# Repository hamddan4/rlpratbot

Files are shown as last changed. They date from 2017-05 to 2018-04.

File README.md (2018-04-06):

# rlpratbot

Remote Autonomous Transporter

A project to remotely control a small vehicle using a Telegram bot through an Arduino board.

All the schematics are provided in the "Images & Fritzing" folder. Code for the sender and receiver/controller board can be found in the "Code" folder.

This project was part of a university course.

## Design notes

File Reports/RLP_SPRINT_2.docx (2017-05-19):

RAT

A remotely controlled robot that travels to a specified location while avoiding obstacles.
________________________________________________________________

# Project description

The sole purpose of RAT is to transport an object from one point to another. To accomplish this, RAT will wait until it remotely receives a coordinate to go to, then it'll travel there while avoiding any obstacle in the way. It'll also periodically send its current position to the remote controller, so that the robot can be localized at any time.

Below is a detailed description on how we plan to carry out these functionalities:

- Movement: RAT will be able to move using two DC motors (with wheels attached) controlled by a motor driver board. This setup makes it possible for RAT to move forwards and backwards with an adjustable speed. Rotation will be accomplished by activating only one of the two motors.
- Remotely sending and receiving data: We'll use two transceivers controlled by two Arduino UNO boards. One of them will be located in the robot, and the other will be connected to the computer used to send the coordinates and receive the current robot position.
- Route tracing: When RAT receives an objective coordinate, it'll get its current position and orientation using a GPS and a magnetometer respectively. It'll then trace a straight line from its current position to the objective coordinate, calculate the direction, and rotate accordingly. When it determines it's facing the correct direction, it'll start moving forward until an obstacle is found or the objective coordinates have been reached. Periodical checks will be made to make sure it's not going offtrack.
- Obstacle avoiding: RAT will be able to detect nearby obstacles using a sonar. Once an obstacle is detected, it'll try to overcome it and then resume its original path. We still don't know a lot about how to code this, but we've been promised we're going to be taught.

Note on the limitations of the distance traveled:

The precision of the GPS used is around 3m, so RAT's duty is to land inside an area of 3m around the specified point. Specifying points too close to RAT would make it
The transceiver used has a range of about 100m, so making RAT go towards points farther than that leads to losing all kind of communication with it. It could still, in principle, autonomously get to its objective, and then receive new orders from a different computer nearby.

# Electronic components

- Arduino UNO (2x) (one of them is of our own, it'll be used to send data from the computer to the robot using the transceiver)
- nRF24L01P+ (Transceiver) (2x)
- L293D (Motor Driver Board)
- HC-SR04 (Sonar)
- Adafruit Ultimate GPS Logger Shield
- DC motor (2x)
- Magnetometer (not yet received, it'll not be taken into account for the connections scheme below since we don't know the model)

# Scheme

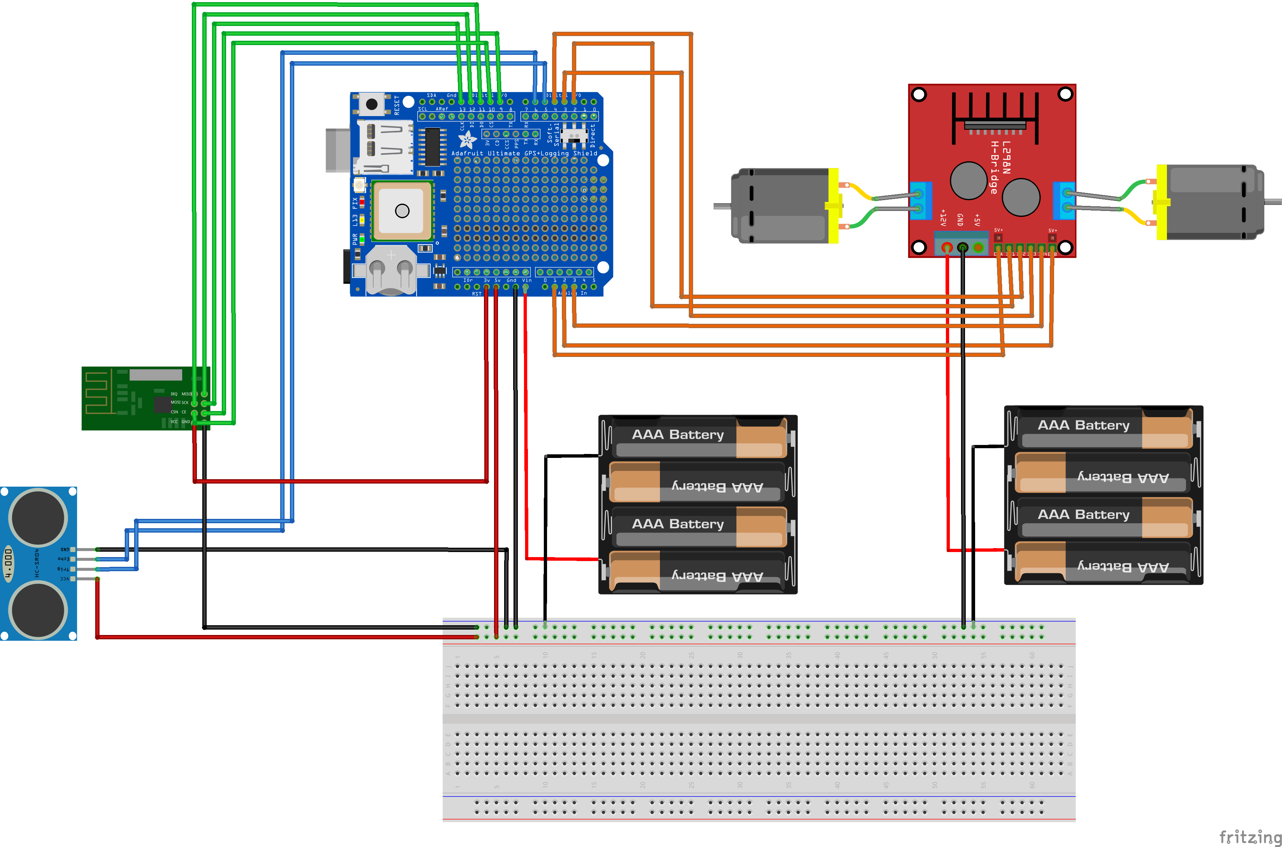
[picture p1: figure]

Notes:

- All red wires go to Vcc (5V for all the components except the transceiver which goes to the 3.3V pin).

- All black wires go to GND.

- All the AAA batteries shown in the scheme are 1.2V AA batteries in actuality.

- The GPS shield uses digital pins 0, 1, 7 and 8.

Connections:

Sonar (blue)

Trigger Pin -> Digital Pin 5 (PWM)

Echo Pin -> Digital Pin 6 (PWM)

Motor Driver (orange)

ENA -> Analogic Pin A1 (Digital Pin 15)

ENB -> Analogic Pin A2 (Digital Pin 16)

IN1 -> Digital Pin 2

IN2 -> Digital Pin 3 (PWM)

IN3 -> Digital Pin 4

IN4 -> Analogic Pin A3 (Digital Pin 17)

Transceiver (green)

CE Pin -> Digital Pin 9 (PWM)

CSN Pin -> Digital Pin 10 (PWM)

SCK Pin -> Digital Pin 13

MOSI Pin -> Digital Pin 11 (PWM)

MISO Pin -> Digital Pin 12

# Extra components and 3D pieces

- Wheel for DC motor (2x) They'll be connected to the motors to allow RAT to move on ground.
- Caster wheel A support wheel which will be placed on the back of the robot.
- 4 AA Battery Holder (2x) Used to conveniently hold 4 AA batteries in series so that they produce 5V of voltage.
- 1.2V AA Rechargeable Battery (8x) 4 of them them are to power the Arduino board, the other 4 to power the motors.

List of 3D pieces:

No. | Description | Image

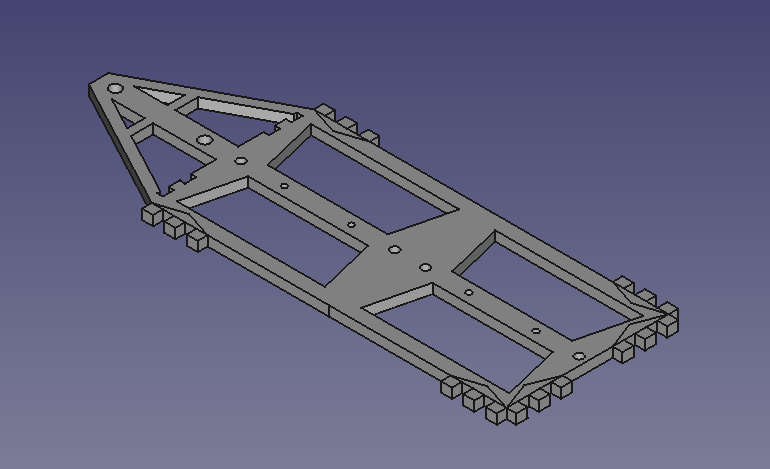
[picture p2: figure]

1 | Base of the robot. Here we'll attach both the Battery Holder and the Caster Wheel.

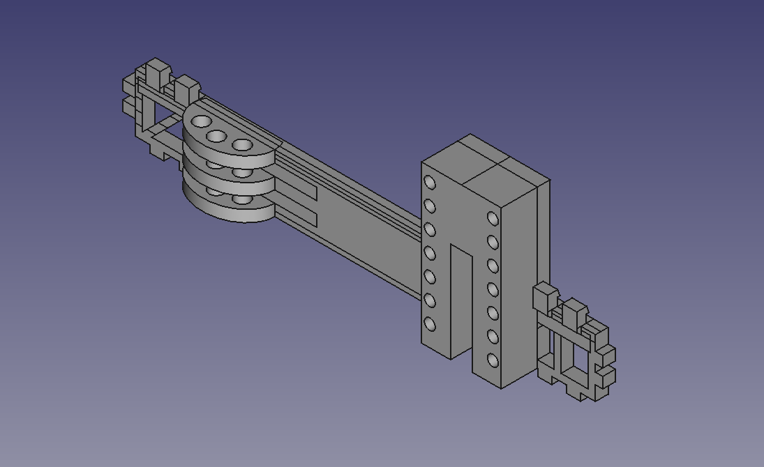
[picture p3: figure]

2 | Laterals of the robot. Here we'll attach the motors. ...and a mystery piece, coming up next sprint!

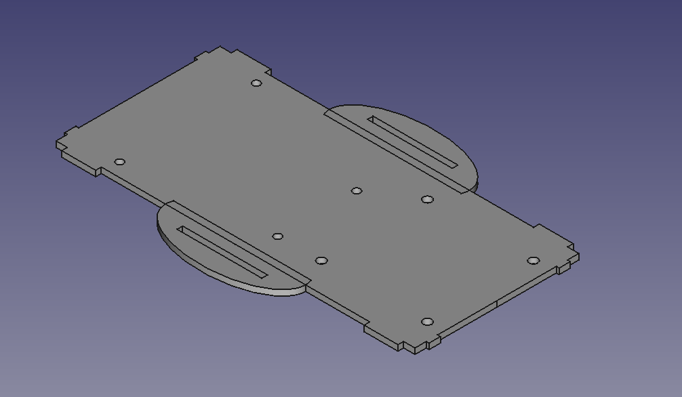
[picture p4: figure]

3 | Cover of the robot. Here we'll attach both the Arduino UNO board and the Motor Driver Board.

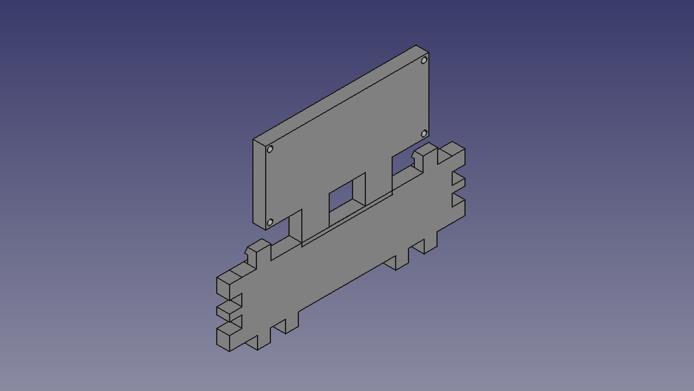
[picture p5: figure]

4 | Front of the robot. Here we'll attach the Sonar.

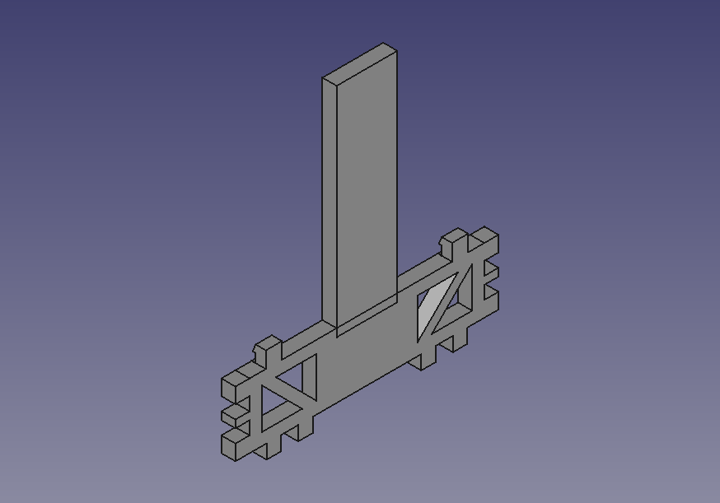
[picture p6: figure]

5 | Back of the robot. Here we'll attach the Transceiver.

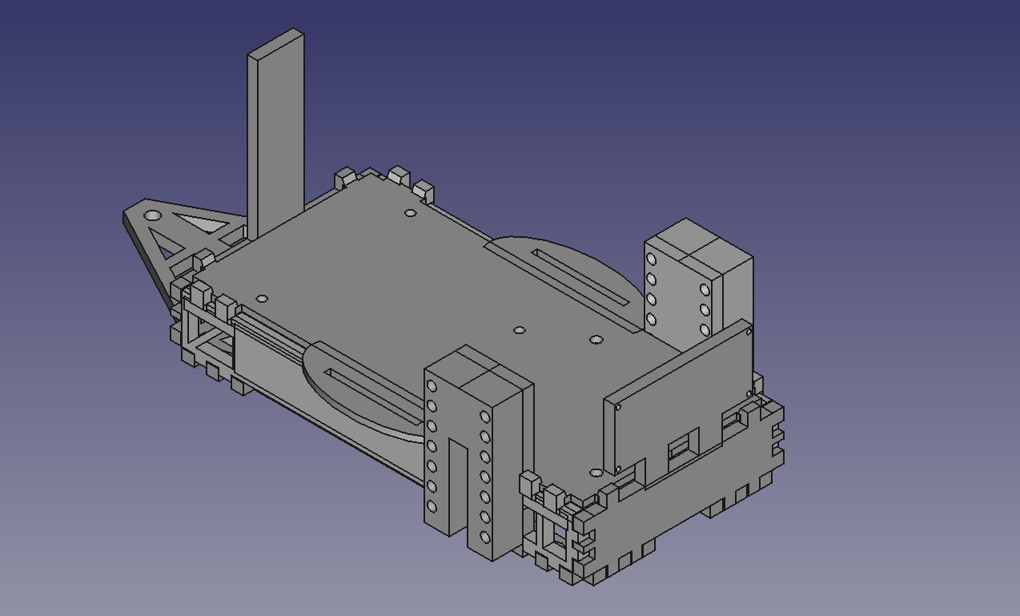
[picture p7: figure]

ALL | Overall view of the structure.

Note:

We'll join all the pieces together by sticking their respective hooks and ledges with superglue. However, the cover will use Snap-fit to make it easy to put it in and out, since the Arduino Board and the batteries are inside the robot, and we'll want to have easy access to them.

# Foreseen risks and contingency plan

No. | Description | Probability | Impact | Contingency plan
1 | We don't receive the magnetometer | Low | High | Use trial and error to determine the current orientation.
2 | The magnetometer hasn't got enough precision | Medium | Medium | Direction checks should be done very frequently (stopping the robot).
3 | The motors are not firmly fixed (and they make the robot tilt to the right or left instead of going in a straight line) | Medium | Medium | Redesign motor attachment to the robot and/or use superglue.
4 | Misalignment or rupture of the snap-fit joints (between the cover and lateral 3D pieces). | High | Low | 1. Redesign the joints and reprint the pieces. 2. (In case 1 keeps failing) Design and print a hinge which will be used to attach the cover with the laterals. 3. (In case 2 were to fail too) Just come up with a different way of accessing the insides of the robot.
5 | Misalignment or rupture of the joints to be sticked with superglue. | Medium | Medium | Redesign the joints and reprint the pieces.

References

This project has been inspired by the following Internet projects:

(http://www.instructables.com/id/Arduino-Powered-Autonomous-Vehicle/)

(http://www.robotshop.com/letsmakerobots/fundamentals-a-gps-guided-vehicle)

http://www.instructables.com/id/Arduino-Powered-Autonomous-Vehicle/

http://www.robotshop.com/letsmakerobots/fundamentals-a-gps-guided-vehicle

(http://www.instructables.com/id/Arduino-Powered-Autonomous-Vehicle/)

(http://www.robotshop.com/letsmakerobots/fundamentals-a-gps-guided-vehicle)

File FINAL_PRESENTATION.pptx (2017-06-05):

## RAT

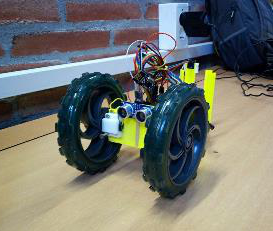
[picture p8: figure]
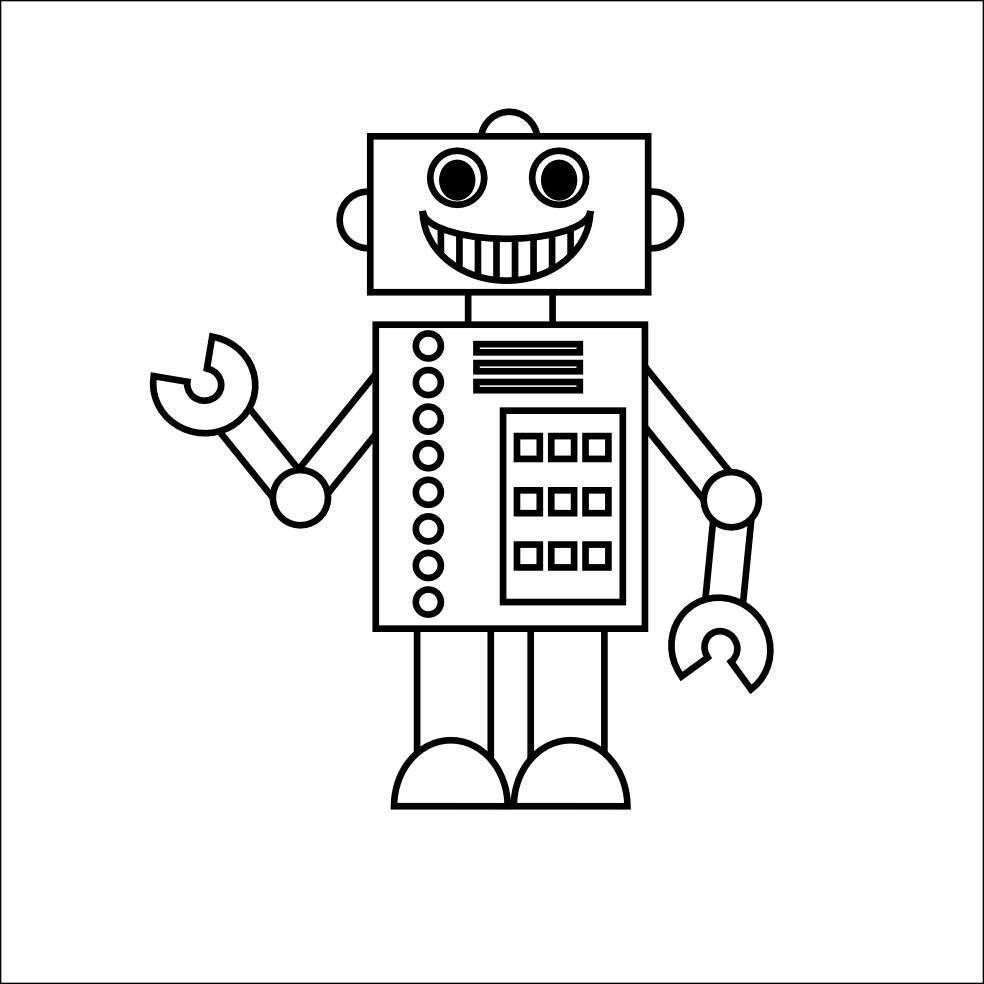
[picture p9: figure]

Adrià Rico Blanes (1391488)
Daniel Azemar i Carnicero (1390451)
Sergi Pous Mateo (1390450)
Jialuo Chen (1390203)

#Cotxe autònom controlat via Transceiver per un ordinador, utilitzarà sensors d’orientació i GPS per saber on està en cada moment.

Robòtica, llenguatge I planificació – Enginyeria informàtica - uab

## Esquema de components

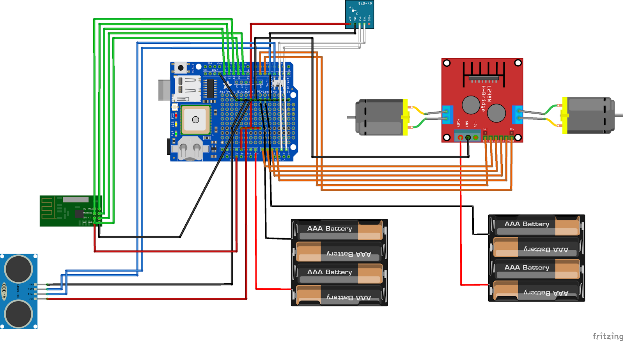
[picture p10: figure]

## 3D Design

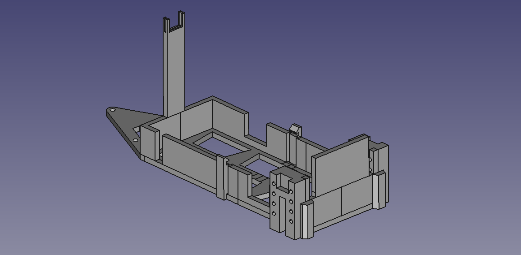
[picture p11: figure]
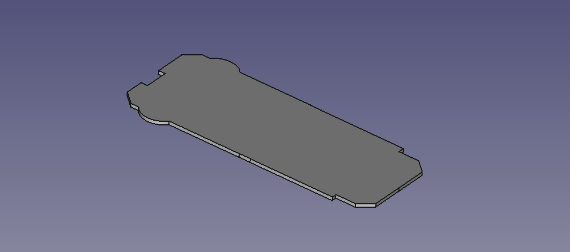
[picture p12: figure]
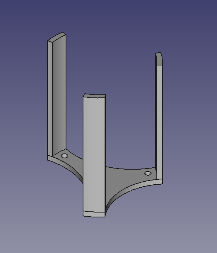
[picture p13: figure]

## 3D Design

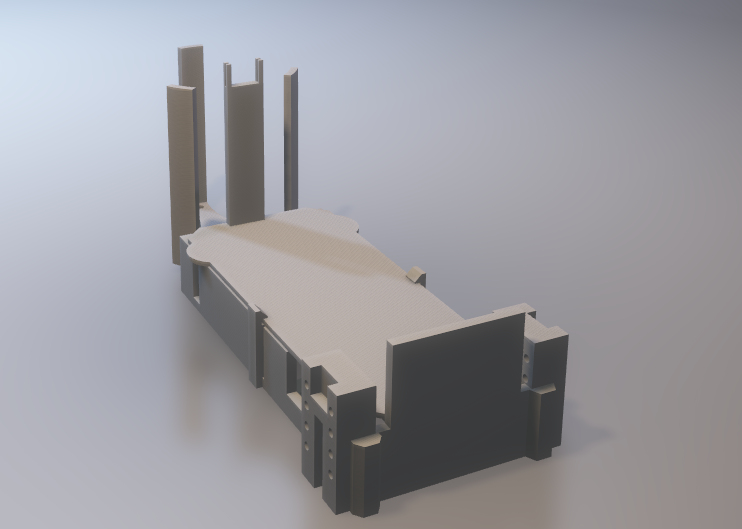
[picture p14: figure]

## 3D Design

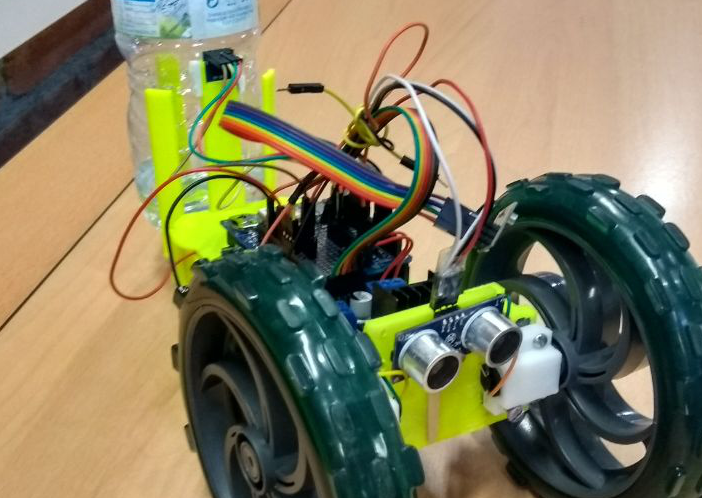
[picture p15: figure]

## Programació

Obstacle?

Order type

Loop

Get GPS

Get SONAR

Yes

OBSTACLE AVOIDANCE

Go to location

Angle OK?

Speed change

Change speed

Yes

Avoiding?

No

Movement

Obey

Get Magnetometer

Calculate angle with obj

Yes

Correct angle

No

Go straight

Are we at position yet?

No

Get Transceiver

Update order

Yes

No

STOP MOTORS

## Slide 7

Obstacle Avoidance

Calibration

Backwalking

Rotation L

Forward Walking

Calibration

Rotation R

## FOTOS

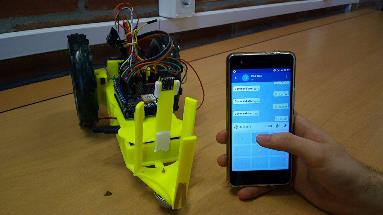
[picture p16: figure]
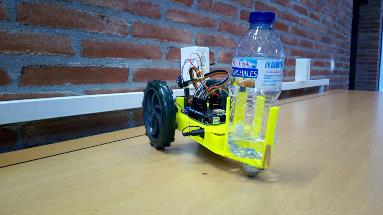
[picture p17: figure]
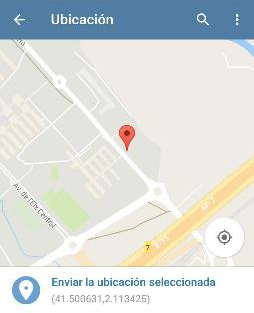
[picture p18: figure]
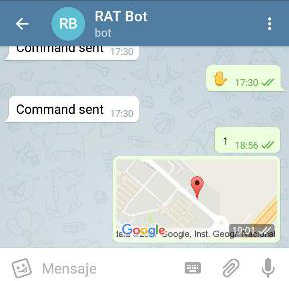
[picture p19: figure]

## FOTOS I VIDEO

#AQUÍ FOTOS

#AQUÍ ENLLAÇ AL VIDEO DEMO

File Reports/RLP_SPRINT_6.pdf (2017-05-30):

# RAT

Remote Autonomous Transporter
(formerly CAT, "Coche Autónomo Teledirigido") A remotely controlled robot that travels to a specified location while avoiding obstacles.
Daniel Azemar | 1390451
Jialuo Chen | 1390203
Sergi Pous | 1390450
Adrià Rico | 1391488

PROJECT SPRINT #2.
DATE: 03 May 2017

RAT

# Table of Contents

Project description | 3
Electronic components | 4
Scheme | 6
Extra components and 3D pieces | 9
Algorithms | 17
Initial objectives and fulfilled objectives | 21
Annex: RAT WAITER | 22
Annex: pictures and videos of the development of RAT | 24

RAT

# RAT

A remotely controlled robot that travels to a specified location while avoiding obstacles.
______________________________________________________________

Note: amendments from sprint 4 are written in blue.

Project description
The sole purpose of RAT is to transport an object from one point to another. To accomplish this, RAT will wait until it remotely receives a coordinate to go to, then it'll travel there while avoiding any obstacle in the way. It'll also periodically send its current position to the remote controller, so that the robot can be localized at any time. Alternatively, RAT will also be able to be manually controlled.

Below is a detailed description on how we plan to carry out these functionalities:

- Movement:
RAT will be able to move using two DC motors (with wheels attached) controlled by a motor driver board. This setup makes it possible for RAT to move forwards and backwards with an adjustable speed. Rotation will be accomplished by activating only one of the two motors.
- Remotely sending and receiving data:
We'll use two transceivers controlled by two Arduino UNO boards.
One of them will be located in the robot, and the other will be connected to the computer used to send the coordinates and receive the current robot position.
- Route tracing:
When RAT receives an objective coordinate, it'll get its current position and orientation using a GPS and a magnetometer respectively. It'll then trace a

RAT straight line from its current position to the objective coordinate, calculate the direction, and rotate accordingly. When it determines it's facing the correct direction, it'll start moving forward until an obstacle is found or the objective coordinates have been reached. Periodical checks will be made to make sure it's not going offtrack.
- Obstacle avoiding:
RAT will be able to detect nearby obstacles using a sonar. Once an obstacle is detected, it'll try to overcome it and then resume its original path. We still don't know a lot about how to code this, but we've been promised we're going to be taught.
- Manual remote control:
RAT will be able to be remotely controlled via a Telegram bot with a simple button interface. The computer running the bot must also be connected via USB to the Arduino used to send signals to RAT. Alternatively, it’ll also be possible to manually control RAT directly from the computer.

Note on the limitations of the distance traveled:

The precision of the GPS used is around 3m, so RAT's duty is to land inside an area of 3m around the specified point. Specifying points too close to RAT would make it The transceiver used has a range of about 100m, so making RAT go towards points farther than that leads to losing all kind of communication with it. It could still, in principle, autonomously get to its objective, and then receive new orders from a different computer nearby.

RAT

Electronic components

- Arduino UNO (2x) (one of them is of our own, it'll be used to send data from the computer to the robot using the transceiver)
- nRF24L01P+ (Transceiver) (2x)
- L293D (Motor Driver Board)
- HC-SR04 (Sonar)
- Adafruit Ultimate GPS Logger Shield
- DC motor (2x)
- GY-271 (Magnetometer)

RAT

Scheme
RAT

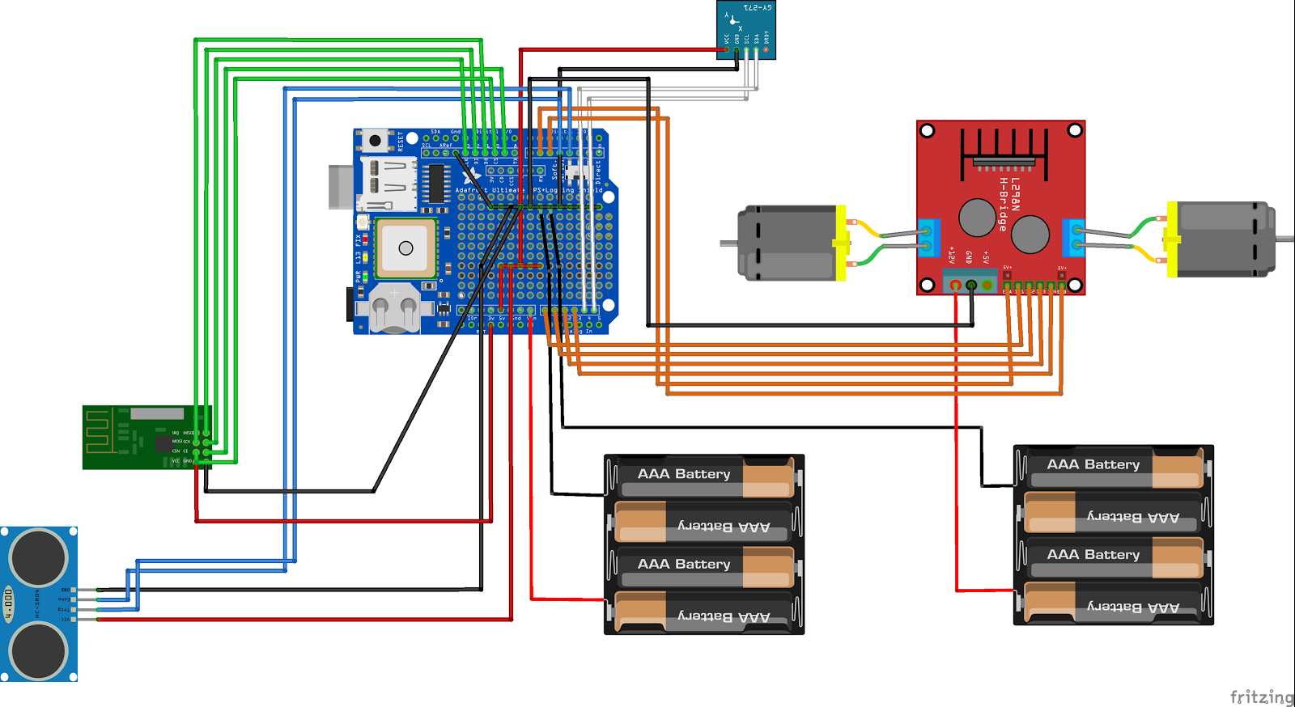
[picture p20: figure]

Notes:

- All red wires go to Vcc (5V for all the components except the transceiver which goes to the 3.3V pin).
- All black wires go to GND.
- All the AAA batteries shown in the scheme are 1.2V AA batteries in actuality.
- The GPS shield uses digital pins 0, 1 (for the direct connection), 7 and 8 (for the soft serial connection).

RAT

Connections:

Sonar (blue)

Trigger Pin -> Digital Pin 3 (PWM)

Echo Pin -> Digital Pin 4

Motor Driver (orange)

ENA -> Digital Pin 5 (PWM)

ENB -> Digital Pin 6 (PWM)

IN1 -> Analog Pin A0 (Digital Pin 15)

IN2 -> Analog Pin A1 (Digital Pin 15)

IN3 -> Analog Pin A2 (Digital Pin 16)

IN4 -> Analog Pin A3 (Digital Pin 17)

Transceiver (slave, green)

CE Pin -> Digital Pin 9 (PWM)

CSN Pin -> Digital Pin 10 (PWM)

SCK Pin -> Digital Pin 13

MOSI Pin -> Digital Pin 11 (PWM)

MISO Pin -> Digital Pin 12

RAT

Magnetometer (white)

SCL Pin -> Analog Pin A5 (I2C Clock)

SDA Pin -> Analog Pin A4 (I2C Data)

Master (computer)

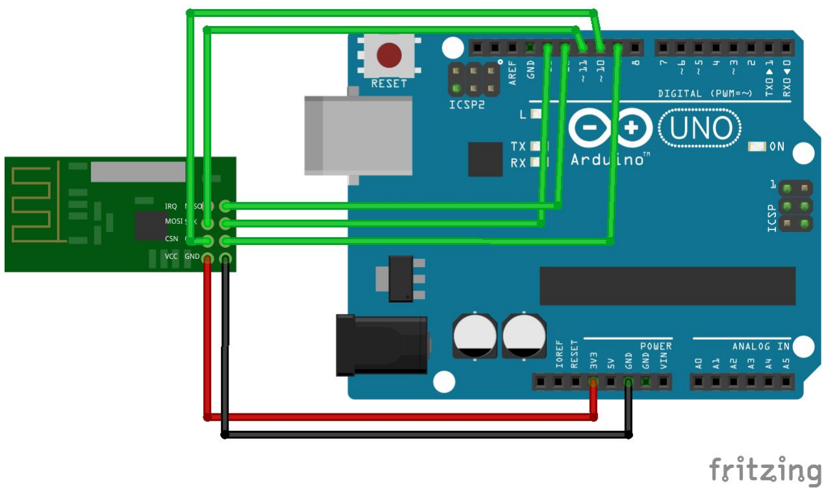
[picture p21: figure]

RAT

Connections:

USB alimentation

Transceiver (master, green)

CE Pin -> Digital Pin 9 (PWM)

CSN Pin -> Digital Pin 10 (PWM)

SCK Pin -> Digital Pin 13

MOSI Pin -> Digital Pin 11 (PWM)

MISO Pin -> Digital Pin 12

Extra components and 3D pieces

- Wheel for DC motor (2x)
They'll be connected to the motors to allow RAT to move on ground.
- Caster wheel
A support wheel which will be placed on the back of the robot.
- 4 AA Battery Holder (2x)
Used to conveniently hold 4 AA batteries in series so that they produce 5V of voltage.
- 1.2V AA Rechargeable Battery (8x)

### 4 of them them are to power the Arduino board, the other 4 to power the

motors.

RAT

List of 3D pieces:
V1 problems and announcement of V2:

After having seen the errors that V1 had, we are encouraged by a new design and a second print, this time with the aim to be more consistent.

The main purpose of this reprint isn’t to fix the errors that we’ve detected, but to generate fewer pieces (for example, the box holding the batteries is now only one piece, not 5 like before, one per wall).

We think that’ll fix many problems when joining the pieces (we’ve struggled a lot with V1) and it also makes the modelling is easier.

Below, we’ll show the errors in V1 within the table of pieces of the last sprint:

No. | Description | Image

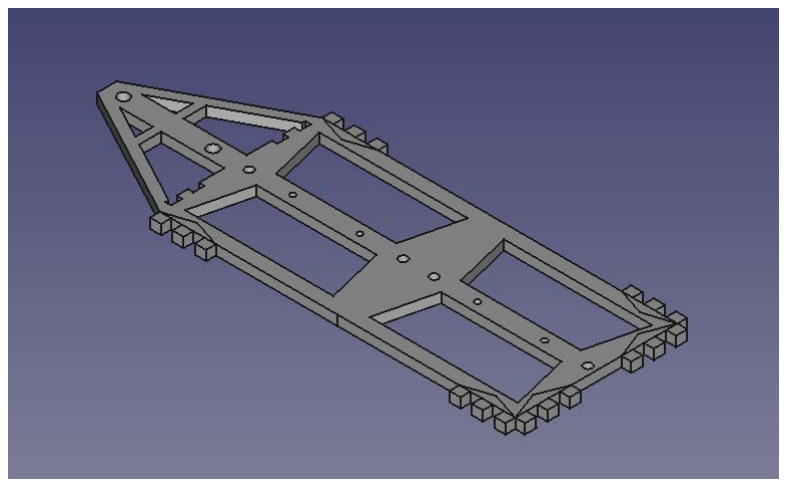
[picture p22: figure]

1 | Base of the robot. Here we'll attach both the Battery Holder and the Caster Wheel.

RAT

| Errors detected: 1. We put one hole of the caster wheel in the wrong place. We had to drill it. 2. We realized that maybe we needed 10 batteries instead of 8 to supply enough power to the Arduino and all sensors. We had to expand the base.

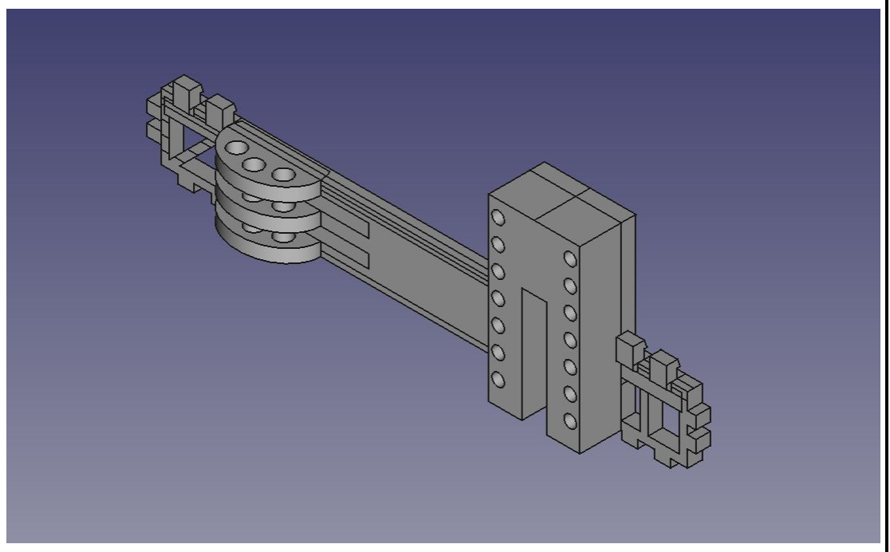
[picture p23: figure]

2 Laterals of the robot. | Here we'll attach the motors. ...and a mystery piece, coming up next sprint!

Errors detected:

### 1. The batteries didn’t have the holes to pass the wires in the correct

place. Had to drill it.

### 2. We missed a protrusion in the motors so we had to melt the piece to

make them fit.
3. The “fit-in” piece to hold the cover wasn’t printed precisely enough; the cover did not fit.

RAT

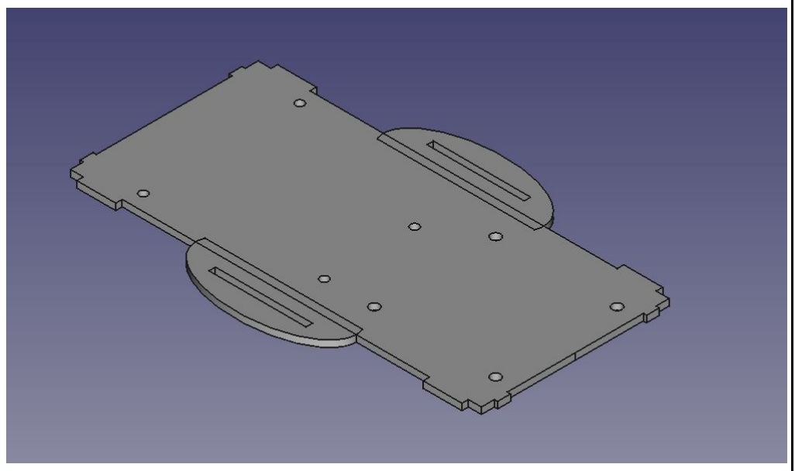
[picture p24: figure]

3 | Cover | of the robot.

Here we'll attach both the Arduino UNO board and
the Motor Driver Board.

Errors detected:

### 1. The holes where the chips and boards had to fit were not precisely

placed. We had to struggle to pass the screws through the board’s holes and as a result they were under a lot of pressure due to the tilt of the screws.

4 | Front of the robot. Here we'll attach the Sonar.


| Errors detected: 1. The holes where the sonar had to fit in were so close to the borders that the printer skipped the thin wall that was separating them. The sonar is now hold by a rubber band.

RAT

5 | Back of the robot. Here we'll attach the Transceiver.


| Errors detected: 1. The transceiver holder is way too small.
ALL | Overall view of the structure.


| Errors detected: 1. The batteries in the inside were too tall. The cover couldn’t fit at all.

RAT

Note:

We'll join all the pieces together by sticking their respective hooks and ledges with superglue. However, the cover will use Snap-fit to make it easy to put it in and out, since the Arduino Board and the batteries are inside the robot, and we'll want to have easy access to them.


For future works!

If you’re gonna use silicone to stick the
pieces together,

DO NOT USE KITCHEN SILICONE! The results are AWFUL.

V2 pieces:

With all that we’ve mentioned before, here are the new pieces that will hopefully fix all of those problems at once.

No. | Description | Image


1 | Base of the robot. Here we'll attach both the Battery Holder and the Caster Wheel, and sonar, and transceiver, and motors. ...and a mystery piece, coming up next page!

RAT

| Errors detected: 1. Well, the truth is that this piece is already printed. And it has errors… We wanted to print it all in one piece so that we didn’t have to join the pieces (see the sticking problems we had before). The problem came with the “fit-in” piece to hold the cover: Just bending it a little was enough to make it break.


2 Cover of the robot. | Here we'll attach both the Arduino UNO board and the Motor Driver Board.


3. And… Ladies and | Gentlemen: With all of you… the MYSTERY PIECE. What is its purpose? What was it made for? Will it be useful for the robot at all? SEE RAT WAITER!

RAT

Algorithms
Code on RAT

Sonar

The sonar sends a high-frequency sound wave, then it starts a timer. When the sound wave bounces off an object and returns to the device, the timer stops and the time passed is sent to the Arduino board.

To transform this time to distance, we have divided it by 2 (because the sound travels forward, then backwards), converted it to seconds and multiplied it by the speed of sound.

Because the sonar signal can be quite unstable, we applied a Kalman filter to it.


A graph showing the actual distance obtained by the magnetometer (blue) and the Kalman filtering (orange). As you can see, Kalman helps to avoid the sudden peaks towards 0 (which are caused by the GPS field taking up all the resources during relocation)

RAT

GPS

The GPS shield automatically gives us the current location of RAT, thanks to the official library.

Transceiver

We used a very simple protocol to transmit information from the computer to RAT.

First of all, to ensure that no messages are lost, every time we send one we wait for an acknowledgement, and if none is received, we send the message again.

If the first byte received by RAT is not 255, it’s interpreted as a manual control function, which could be one of the following:

Code | Meaning
0 Rotate left forward
1 Go forward
2 Rotate right forward
3 Stop
4 Rotate left backwards
5 Go backwards
6 Turn right backwards
7 Increase speed
8 Decrease speed

If the first byte received is 255, it means the computer’s about to send a location.

RAT will wait for 4 more bytes to arrive and cast them to a float representing the latitude, then it’ll wait for another 4 bytes and cast them to a float representing the longitude. It’ll then enter the automatic mode.

RAT

Magnetometer

The magnetometer gives us the intensity of the magnetic field on each axis.

Since we’re only interested in rotation around the axis perpendicular to the ground, given how the magnetometer is placed on the robot, we can completely ignore the Y axis, and calculate the angle of the magnetic field by doing the arctan2(Z_axis, X_axis).

Motors

We control the motors through the motor board. We send the speed of each motor through the ENA and ENB pins. We control each motor using its two designed pins. Here’s a table showing how we rotate each motor the desired direction:

Desired effect | Pin 1 | Pin 2
Move forwards | LOW | HIGH
Move backwards | HIGH | LOW
Stop | LOW | LOW
Then, to move RAT, we combine the two motors’ rotation. Here’s a table of the rotation of each motor to make RAT move how we desire:
Desired effect | Left motor rotation | Right motor rotation
Go forward | Forward | Forward
Turn left forward | Stopped | Forward
Turn right forward | Forward | Stopped
Go backwards | Backwards | Backwards
Turn left backwards | Stopped | Backwards
Turn right backwards | Backwards | Stopped

RAT

Rotate clockwise about itself | Forward | Backwards
Rotate anti-clockwise about itself | Backwards | Forward
Stop | Stopped | Stopped

Automatic mode

When RAT enters automatic mode, some calculations must be made to decide where to point to go to the desired location.

First, the current position and orientation must be obtained (as previously described). Then, the objective angle is calculated using arctan2(current_longitude
- objective_longitude, current_latitude - objective_latitude). The order here is important, because we calibrated the magnetometer so that 0º correspond to looking straight to the north, which is the latitude axis. Thus, this axis would correspond to the standard X axis on the cartesian plane, and longitude would correspond to the Y axis, so arctan2(Y,X) corresponds to the previous expression.

Once the objective angle is known, we calculate which way is faster, if rotating to the left or to the right, and RAT rotates until a certain threshold is met, then it starts moving forwards towards the target coordinates until it arrives, periodically checking if it’s on the right course and recalculating its objective angle given its actual position.

Below is an overview of the code flow

RAT


Code on the computer (master)

Telegram bot

The computer must be running a Telegram bot server for remote control via Telegram to be possible. The program accepts some input from the telegram API and parses it. If the message received is a location, it sends the magic 255 code (previously mentioned) to the Arduino board via the serial port (USB), and then 8 bytes corresponding to 2 floats which represent the longitude and latitude. If the command received is a manual control action, its code is sent directly via the serial port.

Arduino

The code running on the Arduino connected to the computer is pretty simple. It just listens to the serial port, and whenever it receives a byte, it forwards it to RAT via the transceiver. If the transceiver were to not acknowledge a byte, it is sent again. All other data processing (such as interpreting the coordinates) is done on the RAT code.

RAT

Initial objectives and fulfilled objectives
No. | Description | Fulfilled?
1 | Remote control via computer | Yes, but you have to send to commands manually through Python, we didn’t develop a GUI.
2 | Remote control via Telegram bot | Yes, completely functional.
3 | Obstacle avoiding | Kind of. We stop and wait until the obstacle is not there anymore. The original objective was to go around them.
4 Autonomous movement towards a | specific coordinate | Kind of. RAT correctly turns and points to the correct direction (with an error of ±10º), but it can get lost if there are interferences in the magnetic field. Also, because the motors are not powerful enough, it sometimes can’t manage to turn, never gets to the objective angle and stops indefinitely.

RAT

# Annex: RAT WAITER

MYSTERY PIECE

Presentation:

Have you ever thought it’s too damn work going down stairs for a soda when you are thirsty at your office correcting exams?

Isn’t it tedious meet students at the corridor when you just want to go to the coffee for a beer?

WORRY NO MORE!

INTRODUCING RAT WAITER


With the new bot we can control RAT in two ways: Manual or Autonomous.

RAT

# Annex: pictures and videos of the development of RAT

Here we’ll show some pictures of our RAT.


The problems with the screws. It’s not appreciable yet, but the chips could eventually break if they diverge too much.

RAT


The batteries of the robot. They fit perfectly!

Our robot once (almost) fully assembled. The magnetometer just came yesterday and we’ve not been able to test it!

RAT


And here is the other transceiver, which is connected to the computer running the Telegram bot.

Here is the V2 base piece just coming out from the oven.

RAT


And here is the broken part, just coming out from the oven.


Final prototype with brand new wheels and motors, and 3D pieces.

RAT


Here it is carrying a water bottle.

And here it is controlled by mobile phone.

RAT

Here are some videos demonstrating what RAT is capable of doing at the moment:

First communication test with Telegram bot: https://youtu.be/EcW7nlJUPmk Remote controlling + obstacle detecting: https://youtu.be/hFyf0Mygbd4 Autonomous controlling with GPS and Magnetometer: https://youtu.be/UaKTNJVKUZE

RAT

# References

This project has been inspired by the following Internet projects:

http://www.instructables.com/id/Arduino-Powered-Autonomous-Vehicle/

http://www.robotshop.com/letsmakerobots/fundamentals-a-gps-guided-vehicle

RAT

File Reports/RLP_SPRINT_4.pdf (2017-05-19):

# RAT

Remote Autonomous Transporter
(formerly CAT, "Coche Autónomo Teledirigido") A remotely controlled robot that travels to a specified location while avoiding obstacles.
Daniel Azemar | 1390451
Jialuo Chen | 1390203
Sergi Pous | 1390450
Adrià Rico | 1391488

PROJECT SPRINT #2.
DATE: 03 May 2017

RAT

# Table of Contents

Project description | 3
Electronic components | 4
Scheme | 6
Extra components and 3D pieces | 9
Foreseen risks and contingency plan | 17
RAT WAITER | 18
ANNEX | 20

RAT

# RAT

A remotely controlled robot that travels to a specified location while avoiding obstacles.
______________________________________________________________

Note: amendments from sprint 4 are written in blue.

Project description
The sole purpose of RAT is to transport an object from one point to another. To accomplish this, RAT will wait until it remotely receives a coordinate to go to, then it'll travel there while avoiding any obstacle in the way. It'll also periodically send its current position to the remote controller, so that the robot can be localized at any time. Alternatively, RAT will also be able to be manually controlled.

Below is a detailed description on how we plan to carry out these functionalities:

- Movement:
RAT will be able to move using two DC motors (with wheels attached) controlled by a motor driver board. This setup makes it possible for RAT to move forwards and backwards with an adjustable speed. Rotation will be accomplished by activating only one of the two motors.
- Remotely sending and receiving data:
We'll use two transceivers controlled by two Arduino UNO boards.
One of them will be located in the robot, and the other will be connected to the computer used to send the coordinates and receive the current robot position.
- Route tracing:
When RAT receives an objective coordinate, it'll get its current position and orientation using a GPS and a magnetometer respectively. It'll then trace a

RAT straight line from its current position to the objective coordinate, calculate the direction, and rotate accordingly. When it determines it's facing the correct direction, it'll start moving forward until an obstacle is found or the objective coordinates have been reached. Periodical checks will be made to make sure it's not going offtrack.
- Obstacle avoiding:
RAT will be able to detect nearby obstacles using a sonar. Once an obstacle is detected, it'll try to overcome it and then resume its original path. We still don't know a lot about how to code this, but we've been promised we're going to be taught.
- Manual remote control:
RAT will be able to be remotely controlled via a Telegram bot with a simple button interface. The computer running the bot must also be connected via USB to the Arduino used to send signals to RAT. Alternatively, it’ll also be possible to manually control RAT directly from the computer.

Note on the limitations of the distance traveled:

The precision of the GPS used is around 3m, so RAT's duty is to land inside an area of 3m around the specified point. Specifying points too close to RAT would make it The transceiver used has a range of about 100m, so making RAT go towards points farther than that leads to losing all kind of communication with it. It could still, in principle, autonomously get to its objective, and then receive new orders from a different computer nearby.

Electronic components

- Arduino UNO (2x) (one of them is of our own, it'll be used to send data from the computer to the robot using the transceiver)
- nRF24L01P+ (Transceiver) (2x)
- L293D (Motor Driver Board)
- HC-SR04 (Sonar)
- Adafruit Ultimate GPS Logger Shield

RAT

- DC motor (2x)
- GY-271 (Magnetometer)

RAT

Scheme
RAT


Notes:

- All red wires go to Vcc (5V for all the components except the transceiver which goes to the 3.3V pin).
- All black wires go to GND.
- All the AAA batteries shown in the scheme are 1.2V AA batteries in actuality.
- The GPS shield uses digital pins 0, 1 (for the direct connection), 7 and 8 (for the soft serial connection).

Connections:

Sonar (blue)

RAT

Trigger Pin -> Digital Pin 3 (PWM)

Echo Pin -> Digital Pin 4

Motor Driver (orange)

ENA -> Digital Pin 5 (PWM)

ENB -> Digital Pin 6 (PWM)

IN1 -> Analog Pin A0 (Digital Pin 15)

IN2 -> Analog Pin A1 (Digital Pin 15)

IN3 -> Analog Pin A2 (Digital Pin 16)

IN4 -> Analog Pin A3 (Digital Pin 17)

Transceiver (slave, green)

CE Pin -> Digital Pin 9 (PWM)

CSN Pin -> Digital Pin 10 (PWM)

SCK Pin -> Digital Pin 13

MOSI Pin -> Digital Pin 11 (PWM)

MISO Pin -> Digital Pin 12

Magnetometer (white)

SCL Pin -> Analog Pin A5 (I2C Clock)

RAT

SDA Pin -> Analog Pin A4 (I2C Data)

Master (computer)


Connections:

USB alimentation

Transceiver (master, green)

CE Pin -> Digital Pin 9 (PWM)

CSN Pin -> Digital Pin 10 (PWM)

SCK Pin -> Digital Pin 13

RAT

MOSI Pin -> Digital Pin 11 (PWM)

MISO Pin -> Digital Pin 12

Extra components and 3D pieces

- Wheel for DC motor (2x)
They'll be connected to the motors to allow RAT to move on ground.
- Caster wheel
A support wheel which will be placed on the back of the robot.
- 4 AA Battery Holder (2x)
Used to conveniently hold 4 AA batteries in series so that they produce 5V of voltage.
- 1.2V AA Rechargeable Battery (8x)

### 4 of them them are to power the Arduino board, the other 4 to power the

motors.

List of 3D pieces:
V1 problems and announcement of V2:

After having seen the errors that V1 had, we are encouraged by a new design and a second print, this time with the aim to be more consistent.

The main purpose of this reprint isn’t to fix the errors that we’ve detected, but to generate fewer pieces (for example, the box holding the batteries is now only one piece, not 5 like before, one per wall).

We think that’ll fix many problems when joining the pieces (we’ve struggled a lot with V1) and it also makes the modelling is easier.

Below, we’ll show the errors in V1 within the table of pieces of the last sprint:

RAT

No. | Description | Image


| Here we'll attach both the Battery Holder and the Caster Wheel.
1 | Base | of the robot.

Errors detected:

### 1. We put one hole of the caster wheel in the wrong place. We had to

drill it.

### 2. We realized that maybe we needed 10 batteries instead of 8 to supply

enough power to the Arduino and all sensors. We had to expand the base.

RAT


2 Laterals of the robot.

Here we'll attach the
motors.

...and a mystery piece,
coming up next sprint!

Errors detected:

### 1. The batteries didn’t have the holes to pass the wires in the correct

place. Had to drill it.

### 2. We missed a protrusion in the motors so we had to melt the piece to

make them fit.
3. The “fit-in” piece to hold the cover wasn’t printed precisely enough; the cover did not fit.


3 | Cover | of the robot.

Here we'll attach both the Arduino UNO board and
the Motor Driver Board.

Errors detected:

### 1. The holes where the chips and boards had to fit were not precisely

placed. We had to struggle to pass the screws through the board’s

RAT

| holes and as a result they were under a lot of pressure due to the tilt of the screws.
4 | Front of the robot. Here we'll attach the Sonar.


| Errors detected: 1. The holes where the sonar had to fit in were so close to the borders that the printer skipped the thin wall that was separating them. The sonar is now hold by a rubber band.


5 | Back of the robot. Here we'll attach the Transceiver.
| Errors detected:

RAT

| 1. The transceiver holder is way too small.
ALL | Overall view of the structure.


| Errors detected: 1. The batteries in the inside were too tall. The cover couldn’t fit at all.

Note:

We'll join all the pieces together by sticking their respective hooks and ledges with superglue. However, the cover will use Snap-fit to make it easy to put it in and out, since the Arduino Board and the batteries are inside the robot, and we'll want to have easy access to them.


For future works!

If you’re gonna use silicone to stick the
pieces together,

DO NOT USE KITCHEN SILICONE! The results are AWFUL.

RAT


V2 pieces:

With all that we’ve mentioned before, here are the new pieces that will hopefully fix all of those problems at once.

No. | Description | Image

RAT


1 | Base | of the robot.

Here we'll attach both
the Battery Holder and
the Caster Wheel, and
sonar, and transceiver,
and motors.

...and a mystery piece,
coming up next page!

Errors detected:

### 1. Well, the truth is that this piece is already printed. And it has

| | errors… We wanted to print it all in one piece so that we didn’t have to join the pieces (see the sticking problems we had before). The problem came with the “fit-in” piece to hold the cover: Just bending it a little was enough to make it break.


2 Cover of the robot.

Here we'll attach both
the Arduino UNO board
and the Motor Driver
Board.

RAT


### 3. And… Ladies and

Gentlemen: With all of
you… the MYSTERY
PIECE.

What is its purpose?
What was it made for?
Will it be useful for the
robot at all? SEE RAT
WAITER!

RAT

Foreseen risks and contingency plan
No. | Description | Probability | Impact | Contingency plan
1 We don't receive the | magnetometer We’ve already received the magnetometer! | Low | High | Use trial and error to determine the current orientation.
2 The magnetometer | hasn't got enough precision | Medium | Medium | Direction checks should be done very frequently (stopping the robot).
3 The motors are not | firmly fixed (and they make the robot tilt to the right or left instead of going in a straight line) We are currently facing this problem. | Medium | Medium | Redesign motor attachment to the robot and/or use superglue. Contingency plan can’t be applied because the problem actually originates from the motors themselves: one seems to have more power than the other. We’re trying to compensate for the difference of power by making them move at slightly different speeds.
4 Misalignment or | rupture of the snap-fit joints (between the cover and lateral 3D pieces). Actually happened, but we’ve redesigned the 3D pieces. | High | Low | 1. Redesign the joints and reprint the pieces. 2. (In case 1 keeps failing) Design and print a hinge which will be used to attach the cover with the laterals. 3. (In case 2 were to fail too) Just come up with a different way of accessing

RAT

| | | | the insides of the robot.
5 Misalignment or | rupture of the joints to be sticked with superglue. Also happened, but again, we redesigned the 3D pieces. | Medium | Medium | Redesign the joints and reprint the pieces.

# RAT WAITER

MYSTERY PIECE

Presentation:

Have you ever thought it’s too damn work going down stairs for a soda when you are thirsty at your office correcting exams?

Isn’t it tedious meet students at the corridor when you just want to go to the coffee for a beer?

WORRY NO MORE!

INTRODUCING RAT WAITER

RAT


With the new bot we can control RAT in two ways: Manual or Autonomous. The latter is not available yet but you can see the concept of what it’s going to be.

RAT

# ANNEX

Here we’ll show some pictures of our RAT.


The problems with the screws. It’s not appreciable yet, but the chips could eventually break if they diverge too much.

RAT


The batteries of the robot. They fit perfectly!

RAT


Our robot once (almost) fully assembled. The magnetometer just came yesterday and we’ve not been able to test it!

RAT


And here is the other transceiver, which is connected to the computer running the Telegram bot.

RAT


Here is the V2 base piece just coming out from the oven.

RAT


And here is the broken part, just coming out from the oven.

Here are some videos demonstrating what RAT is capable of doing at the moment:

First communication test with Telegram bot: https://youtu.be/EcW7nlJUPmk Remote controlling + obstacle detecting: https://youtu.be/hFyf0Mygbd4

RAT

# References

This project has been inspired by the following Internet projects:

http://www.instructables.com/id/Arduino-Powered-Autonomous-Vehicle/

http://www.robotshop.com/letsmakerobots/fundamentals-a-gps-guided-vehicle

RAT

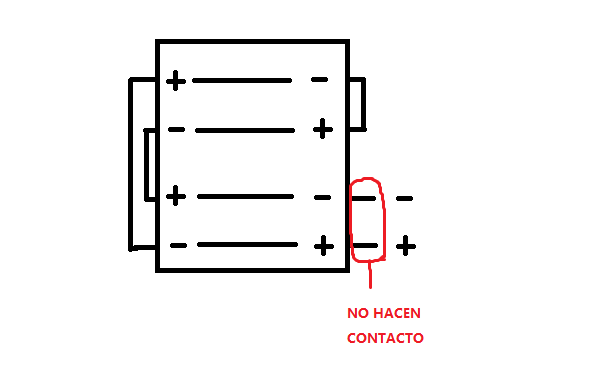
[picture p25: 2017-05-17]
Images & Fritzing/battery holder.png

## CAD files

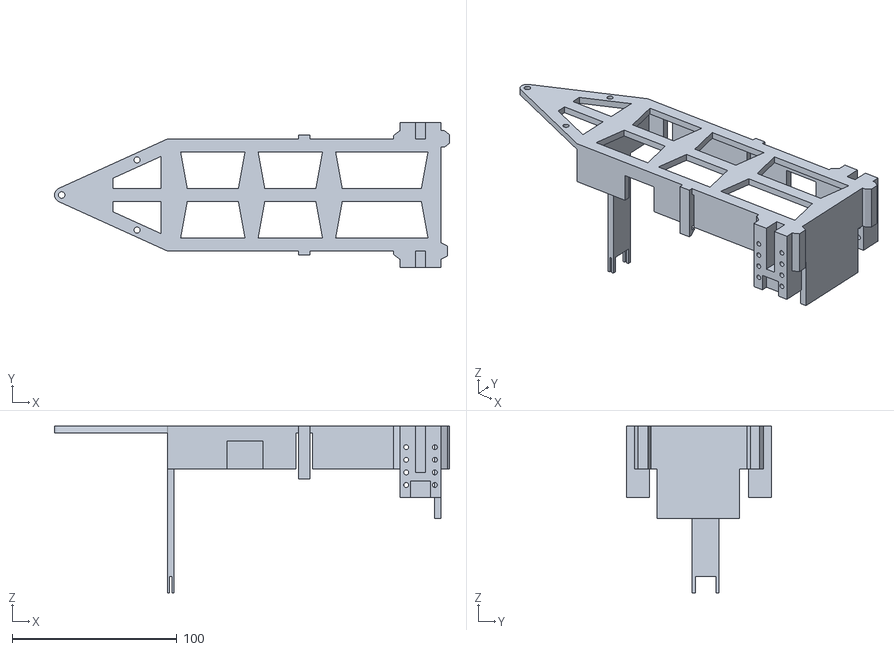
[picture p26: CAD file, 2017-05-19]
3D pieces/base_v2.stl
239.6 x 88.0 x 101.0

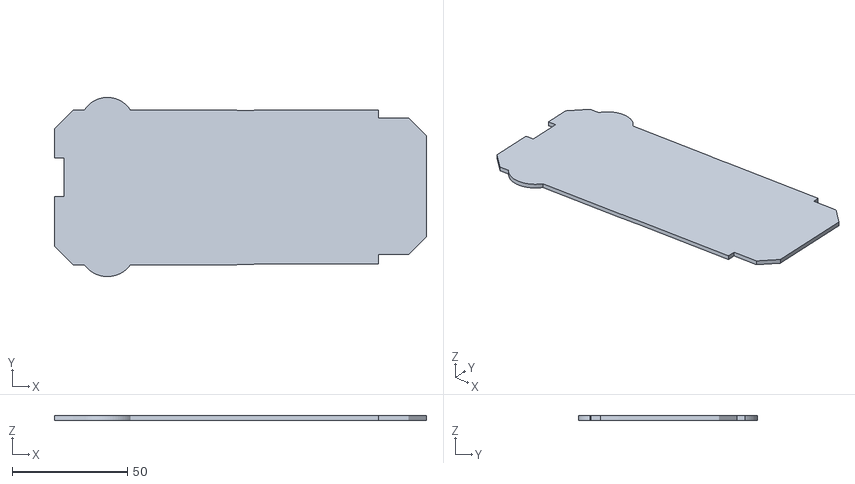
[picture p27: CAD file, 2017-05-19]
3D pieces/tapa_v2.stl
161.7 x 77.9 x 2.00

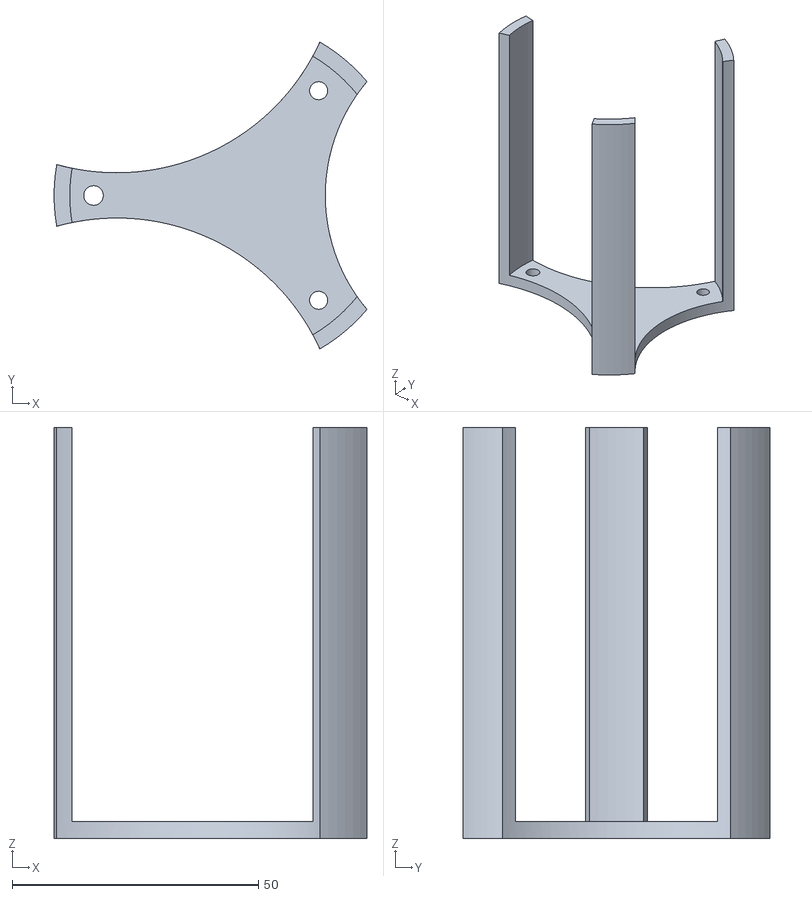
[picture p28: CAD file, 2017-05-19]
3D pieces/mistery_piece_v2.stl
63.6 x 62.4 x 83.5

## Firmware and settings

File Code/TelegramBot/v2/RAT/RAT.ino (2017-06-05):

/*H========================================================================
* FILENAME :        RAT.ino
*
* DESCRIPTION :
*       Main alogirthm that controls the behaviour of the RAT robot. 
* 
* AUTHORS :    RLP Group 09-03
*                 - Daniel Azemar   dani.azemar@gmail.com
*                 - Jialuo Chen     
*                 - Sergi Pous
*                 - Adria Rico
*                 
* START DATE :    Feb 2017
* 
*========================================================================H*/

#include <SimpleKalmanFilter.h>

#include "transceiver.h"//Transceiver
#include "magneto.h"    //Magnetometer
#include "sonar.h"      //Sonar
#include "motors.h"     //Motors
#include "GPS.h"        //GPS
#include "global.h"     //Global functions

//=======================================================
// When Debugging the sensors, use these parameters
// in order to print data through the serial
//=======================================================
const bool print_sonar = false;       //Distance from obstacles
const bool print_magneto = false;     //Angle with the nord
const bool print_motors = false; //debugging not implemented for this sensor/actuator
const bool print_GPS_pos = false;     //Location and Latitude
const bool print_GPS_dist = false;    //Distance from desired location
const bool print_avoidance_stats = true;// Avoidance status debugging

bool enable_GPS = true;     //If you want to work with the GPS, activate these parameter


//=======================================================
// Global Variables to control the avoidance of an object
//=======================================================
typedef enum {CALIBRATE, BCKW,  ROTATE, FORWARD, CALIBRATE2, BACKROTATE, END} avoidance; //This are the steps of the avoidance of an object
typedef enum {ROTATING_RIGHT, ROTATING_LEFT} rotations_avoidance; //To control in which direction are we avoiding an object
boolean avoidance_started = false;      //Boolean that controls some stats
int avoidance_step = CALIBRATE;         //At witch point of the avoidance are we
float angle_calibrated = 0.0;           //Value that stores the angle when calibrated
float angle_rotated = 0.0;              //Value that stores the actual angle when rotation is done
boolean timer_set = false;              //Value that controls the setting of the timer
int actual_millis;                      //Value that stores the actual timing of arduino's clock
int timer_avoidance = 0;                //Value that stores the started timing for a desired step
int actual_rot = ROTATING_RIGHT;        //NOT IMPLEMENTED YET (When this value is changed, the rotations of avoidance change)
int diff_angle_rotated;                 //Difference of angle_calibrated and angle_rotated
const int speed_avoid = 160;            //Speed of the motors when rotating. Needs to be slower bc magnetometer has to move slowly in order to read more reliable values


int LAST_MOV = 0;                       //(i think) Deprecated variable, when you have time, delete it and test the code again


SimpleKalmanFilter simpleKalmanFilter(1, 10, 0.01); //For obtain a precise mean and approximation for sonar measures, we use Kalman Filtering

void setup() {
  Serial.begin(9600);
  setup_transceiver();
  setup_motors();
  setup_sonar();
  setup_magneto();
  if (enable_GPS) setup_GPS();
  moveRAT(STOP,0,0);
}

const int min_vel = 150;                //Max power of motor rotation
const int max_vel = 250;                //Min power of motor rotation
int spd = 200;                          //Arbitrary speed to rotation
int spdPlus = 10;                       //Arbitrary speed boost when necessary
button currentDir;                      //Actual order of the bot (see buttons in motors.h)
bool obstacle = false;                  //Boolean that determines if we are going to crash with an obstacle
bool stopped = false;                   
int angle_tol = 10; // angle error tolerance

bool automatic_for_ever = true;      // WHEN DEBUGGING AUTOMATIC MODE, THIS IS USEFUL
bool automatic = automatic_for_ever; // FALSE IF YOU DONT WANT TO START IN AUTOMATIC MODE
int dest_angle = 0;


// GPS values
double latitude_objective = 0.0;    //When automatic, an objective has to be set
double longitude_objective = 0.0;
double latitude_current = 0.0;     
double longitude_current = 0.0;

//SONAR Values 
float actual_dist = 0.0;
double distance_from_objective = 0.0;

void loop() {
  //====================================================================
  // RETRIEVE SENSORS DATA
  //====================================================================
  //-- GPS -- (latitude and longitude)
  if(enable_GPS){
    GPS_loop();
    latitude_current = get_latitude();
    longitude_current = get_longitude();
  }
  if (print_GPS_dist || print_GPS_pos){
    if(get_fix()){
      if(print_GPS_pos){
        Serial.print(latitude_current, 8);
        Serial.print(" ");
        Serial.print(longitude_current, 8);
        Serial.print(" ");
      }
      distance_from_objective = calc_dist(latitude_current,longitude_current,latitude_objective,longitude_objective);
      if(print_GPS_dist){
        Serial.print(distance_from_objective, 8);
        Serial.print(" ");
      }
    } else {
      Serial.print("Fixing position");
      Serial.print(" ");
    }
  }

  //-- MAGNETOMETER -- (angle)
  int curr_angle = mod(get_yangle() + 90, 360);  
  float e_rotation_angle = get_yangle_rotating(curr_angle);
  float e_rotation_soft_angle = get_yangle_rotating_soft(curr_angle);
  
  if(print_magneto){
      Serial.print(curr_angle);
      Serial.print(" ");
      Serial.print(e_rotation_angle);
      Serial.print(" ");
  }
    
  //-- SONAR -- (distance from an object)
  float detected_dist = getSonarDistance();
  
  if(detected_dist > 3.0){ //this IF is used to correct a possible sonar malfunction when working with GPS
    actual_dist = detected_dist;
  }
  float distance_from_object = simpleKalmanFilter.updateEstimate(actual_dist);
  if (print_sonar){
    Serial.print(actual_dist);
    Serial.print(" ");
    Serial.print(distance_from_object);
    Serial.print(" ");
  }

  //========================================================================================
  //  OBJECT DETECTION AND AVOIDANCE
  //========================================================================================
  obstacle = (distance_from_object < 16) && (currentDir == FWD || currentDir == LFWD || currentDir == RFWD);
  
  if ((obstacle || avoidance_started) && automatic) {
    if(print_avoidance_stats){
            Serial.print("OBJECT");
            Serial.print(" ");
    }
    
    if (not(avoidance_started)){
      avoidance_step = CALIBRATE;
      avoidance_started = true;
    }
    switch(avoidance_step){
      case CALIBRATE:
        //=================
        // 1. CALIBRATING MAGNETOMETER (2s wait)
        //=================
        if (not(timer_set)){
          if(print_avoidance_stats){
            Serial.print("RESETING TIMER ");
          }
          timer_avoidance = millis();
          timer_set = true;
        }
        if(print_avoidance_stats){
            Serial.print("CALIBRATING");
            Serial.print(" ");
        }
        actual_millis = millis();
    
        if ((actual_millis - timer_avoidance) < 2000){
          moveRAT(STOP, 0, 0);
          Serial.print("STOP");
          Serial.print(" ");
        } else {
          angle_calibrated = e_rotation_soft_angle;
          avoidance_step = BCKW;
          timer_set = false;
          if(print_avoidance_stats){
            Serial.print(actual_millis);
            Serial.print(" ");
            Serial.print(timer_avoidance);
            Serial.print(" ");
            Serial.print(angle_calibrated);
            Serial.print(" ");
          }
        }
        
        break;
      case BCKW:
        //=================
        // 2. Safety backwards walk
        //=================
        if (not(timer_set)){
          Serial.print("RESETING TIMER ");
          timer_avoidance = millis();
          timer_set = true;
        }
        if(print_avoidance_stats){
              Serial.print("BACKWARDS");
              Serial.print(" ");
         }
         
        actual_millis = millis();

        if(print_avoidance_stats){
          Serial.print(actual_millis);
          Serial.print(" ");
          Serial.print(timer_avoidance);
          Serial.print(" ");
        }
        if ((actual_millis - timer_avoidance) < 500){
          moveRAT(BCK, spd, spd);
        } else {
          avoidance_step = ROTATE;
          timer_set = false;
          if(print_avoidance_stats){
            Serial.print("DONE");
            Serial.print(" ");
          }
        }
        break;
      case ROTATE:
        //=================
        // 3. ROTATING 90 degrees
        //=================
        if (not(timer_set)){
          Serial.print("RESETING TIMER ");
          timer_avoidance = millis();
          timer_set = true;
        }
        
        if(actual_rot == ROTATING_RIGHT){
            moveRAT(RROT, speed_avoid, speed_avoid);
          } else{
            moveRAT(LROT, speed_avoid, speed_avoid);
        }
          
        diff_angle_rotated = mod(e_rotation_soft_angle - angle_calibrated, 360);

        actual_millis = millis();
        if((diff_angle_rotated > 80 && diff_angle_rotated < 280) && ((actual_millis - timer_avoidance) > 300)){
          avoidance_step = FORWARD;
          timer_set = false;
        }
        if(print_avoidance_stats){
            Serial.print("ROTATE");
            Serial.print(" ");
            Serial.print(diff_angle_rotated);
            Serial.print(" ");
         }
        break;
      case FORWARD:
        //=================
        // 4. MOVING FORWARD
        //=================
        if (not(timer_set)){
          Serial.print("RESETING TIMER ");
          timer_avoidance = millis();
          timer_set = true;
        }
        actual_millis = millis();

        if(print_avoidance_stats){
          Serial.print(actual_millis);
          Serial.print(" ");
          Serial.print(timer_avoidance);
          Serial.print(" ");
        }
        if ((actual_millis - timer_avoidance) < 1000){
          moveRAT(FWD, spd, spd);
        } else {
          avoidance_step = CALIBRATE2;
          timer_set = false;
        }
        if(obstacle){
          moveRAT(STOP, 0, 0);
          //DO SOMETHING MORE BRO!
          /* Explanation for future developers:
           *    We wanted for our robot that it needed to avoid obstacles not only in one direction
           *    (as it turns right at every time) and if it finded an obstacle in this direction,
           *    change the rotation to the other side (with the variable "actual_rot").
           *    
           *    This will be useful if someones improves the code with that modification! 
           *    (Harder than you tink, it needs to check that the 90degrees rotation has been
           *    done correctly, etc etc).
          */ 
        }
        if(print_avoidance_stats){
            Serial.print("FORWARD");
            Serial.print(" obsacle? -> ");
            Serial.print(obstacle);
            Serial.print(" ");
         }
        break;
      case CALIBRATE2:
        //=================
        // 5. CALIBRATING MAGNETOMETER (2s wait)
        //=================
        if (not(timer_set)){
          Serial.print("RESETING TIMER ");
          timer_avoidance = millis();
          timer_set = true;
        }
        if(print_avoidance_stats){
            Serial.print("CALIBRATING2");
            Serial.print(" ");
        }

        actual_millis = millis();

        if(print_avoidance_stats){
          Serial.print(actual_millis);
          Serial.print(" ");
          Serial.print(timer_avoidance);
          Serial.print(" ");
        }
  
        if (((actual_millis - timer_avoidance) < 2000)){
          moveRAT(STOP, 0, 0);
          Serial.print("STOP");
          Serial.print(" ");
        } else {
          angle_calibrated = e_rotation_angle;
          avoidance_step = BACKROTATE;
          timer_set = false;
          if(print_avoidance_stats){
            Serial.print(angle_calibrated);
            Serial.print(" ");
          }
        }
        break;
      case BACKROTATE:
        //=================
        // 6. ROTATING 90 degrees
        //=================
        if (not(timer_set)){
          Serial.print("RESETING TIMER ");
          timer_avoidance = millis();
          timer_set = true;
        }
        if(actual_rot == ROTATING_RIGHT){
            moveRAT(LROT, speed_avoid, speed_avoid);
          } else{
            moveRAT(RROT, speed_avoid, speed_avoid);
        }

        actual_millis = millis();
        
        diff_angle_rotated = mod(e_rotation_angle - angle_calibrated, 360);
        if(diff_angle_rotated > 80 && diff_angle_rotated < 280 && ((actual_millis - timer_avoidance) > 300)){
          avoidance_step = END;
          timer_set = false;
        }
        if(print_avoidance_stats){
            Serial.print("BACKROTATE");
            Serial.print(" ");
            Serial.print(diff_angle_rotated);
            Serial.print(" ");
         }
        break;
      case END:
        //=================
        // 7. FINISING PROCESS (Just reseting all variables in case we detect another obstacle).
        //=================
        if(print_avoidance_stats){
            Serial.print("COMPLETED AVOIDANCE");
            Serial.print(" ");
         }
        avoidance_started = false; 
        avoidance_step = CALIBRATE;
        angle_calibrated = 0.0;
        angle_rotated = 0.0;
        timer_set = false; 
        timer_avoidance = 0;
        //int timer_difference = 0;
        actual_rot = ROTATING_RIGHT;
        break;
      default: 
        break;
    }
    
  } else if (obstacle){
    //Just STOP if we are in remote control mode
    moveRAT(STOP, 0, 0);
    if(avoidance_started){
      avoidance_started = false; 
      avoidance_step = CALIBRATE;
      angle_calibrated = 0.0;
      angle_rotated = 0.0;
      timer_set = false; 
      timer_avoidance = 0;
      //int timer_difference = 0;
      actual_rot = ROTATING_RIGHT;
    }
  }

  //===========================================================================================
  //  (NEW ORDER) DATA RETRIEVE AND ACTUALIZATION
  //===========================================================================================
  data = getData();

  if (newData) {
    
    if (data == SPUP) {
      spd += 10;
      if (spd > MAX_SPD) {
        spd = MAX_SPD;
      }
    } else if (data == SPDN) {
      spd -= 10;
      if (spd < MIN_SPD) {
        spd = MIN_SPD;
      }
    } else { 
      avoidance_started = false;
      if (data == LOCATION) {
        avoidance_started = false;
        automatic = true;
        latitude_objective = getDataFloat();
        longitude_objective = getDataFloat();
      } else {
        automatic = automatic_for_ever; // FALSE IF YOU DONT WANT TO BE IN AUTOMATIC FOR EVER
        currentDir = (button)data;
      }
    }
    if(!automatic){
      if (currentDir == FWD || currentDir == LFWD || currentDir == RFWD) {
        if (!obstacle) {
          moveRAT(currentDir, spd, spd);
        }
      } else {
        moveRAT(currentDir, spd, spd);
      }
    }
  }

  //=========================================================================================================
  //  AUTOMATION OF THE ROBOT
  //=========================================================================================================
  
  //if (automatic && get_fix() && (distance_from_objective > 3) && !avoidance_started){
  
  bool activate_autonomous = false;
  
  if(automatic_for_ever){
    activate_autonomous = (automatic && get_fix() && (distance_from_objective > 3) && !avoidance_started);
  } else {
    activate_autonomous = !avoidance_started;
  }
  
  if(activate_autonomous){ 
    float angle = atan2(longitude_objective-longitude_current, latitude_objective-latitude_current);
    dest_angle = angle * 180/PI;
    dest_angle = mod(dest_angle, 360);
    
    int diff = dest_angle - e_rotation_angle;
    int dir;
    int dist;
    if (abs(diff) < 180) {
      dir = sign(diff);
      dist = abs(diff);
    } else {
      dir = -sign(diff);
      dist = 360 - abs(diff);
    }
    //Serial.println(mod(diff, 360));
    float rotationSpeed = min_vel + dist*(max_vel-min_vel)/180;
    
    if (dist > angle_tol) {
      //Serial.print("Entro ");
      if (dir == -1) {
        //Serial.println("DRETA");
        LAST_MOV = RROT;
        moveRAT(LROT, rotationSpeed, rotationSpeed);
      } else {
        //Serial.println("ESQUERRA");
        LAST_MOV = LROT;
        moveRAT(RROT, rotationSpeed, rotationSpeed);
      }
    } else {
      LAST_MOV = FWD;
      if (!obstacle) {
        currentDir = FWD;
        moveRAT(FWD,spd,spd);
      }
    }
  }
  
 //=================
 Serial.println(" ");
}

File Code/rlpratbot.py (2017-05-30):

# -*- coding: utf-8 -*-

import serial
import time
import telepot
from telepot.loop import MessageLoop
from telepot.namedtuple import ReplyKeyboardMarkup, KeyboardButton, ReplyKeyboardRemove
import struct 


print('hello')

test = False

codes = [u'↶', u'↑', u'↷', u'✋', u'↵', u'↓', u'↳', u'-', u'+']
dir_codes = {c: n for n, c in enumerate(codes)}

if(not test):
    ser = serial.Serial(port='COM8', baudrate=9600)

def handle(msg):
    content_type, chat_type, chat_id = telepot.glance(msg)
    print(content_type, chat_type, chat_id,msg['from']['first_name']+msg['from']['last_name'])



    if content_type == 'location':
        message = 'Sending soda to:\n'
        print(msg['location']['latitude'])
        message += 'latitude: ' + str(msg['location']['latitude']) + '\n'
        message += 'longitude: ' + str(msg['location']['longitude'])
        
        bot.sendMessage(chat_id, message)

        bot.sendMessage(chat_id, "Command sent")
        if(not test):
            ser.write(bytes([255]))
            ser.write(struct.pack("f",msg['location']['latitude']))
            ser.write(struct.pack("f",msg['location']['longitude']))
        
        
    elif content_type == 'text':
        if  msg['text'] == "/start":
            
            message = 'Hello ' + msg['from']['first_name'] + ' ' + msg['from']['last_name'] + '\n'
            message += 'I\'m RAT waiter, a bot that will be used for controlling me also bring you a SODA.\n \n'
            message += 'These are the commands that I can now handle:\n'
            message += '/start welcome and information about me\n'
            message += '/show_commands Show the keyboard to move the me\n'
            message += '/hide_commands Hide the keyboard to move the me\n'
            
            bot.sendMessage(chat_id, message)
            
        elif msg['text'] == '/show_commands':
            message = "Showing it"
            resposta=ReplyKeyboardMarkup(keyboard=[\
            [KeyboardButton(text="↶"), KeyboardButton(text="↑"), KeyboardButton(text="↷")],\
            [KeyboardButton(text="-"), KeyboardButton(text="✋"), KeyboardButton(text="+")],\
            [KeyboardButton(text="↵"), KeyboardButton(text="↓"), KeyboardButton(text="↳")]\
            ])
            bot.sendMessage(chat_id, message, reply_markup = resposta)
            
        elif msg['text'] == '/hide_commands':
            message = "Hiding it"
            resposta = ReplyKeyboardRemove(remove_keyboard = True)
            bot.sendMessage(chat_id, message, reply_markup = resposta)
        elif msg['text'] in codes:
            bot.sendMessage(chat_id, "Command sent")
            if(not test):
                ser.write(bytes([dir_codes[msg['text']]]))
        else:
            bot.sendMessage(chat_id, "Message not recognized")
            
            
        
bot = telepot.Bot('347200641:AAHCedET7_Bf-qaClV-In1FCp8xID9iflYQ')
print(bot.getMe())

MessageLoop(bot, handle).run_as_thread()
print('Listening ...')

while 1:
	time.sleep(10)

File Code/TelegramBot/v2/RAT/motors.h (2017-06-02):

/*H========================================================================
* FILENAME :        motors.h
*
* DESCRIPTION :
*       All function to control the motors.
* 
* AUTHORS :    RLP Group 09-03
*                 - Daniel Azemar   dani.azemar@gmail.com
*                 - Jialuo Chen     
*                 - Sergi Pous
*                 - Adria Rico
*                 
* START DATE :    Feb 2017
* 
*========================================================================H*/

typedef enum {LFWD, FWD, RFWD, STOP, LBCK, BCK, RBCK, SPDN, SPUP, RROT, LROT} button;

#define ENA_PIN 6 // ENA of DC motor driver module attach to pin5 of sunfounder uno board
#define ENB_PIN 5 // ENB of DC motor driver moduleattach to pin6 of sunfounder uno board
#define IN1 14 // left IN1 attach to pin8
#define IN2 15 // left IN2 attach to pin9
#define IN3 16 //right  IN3 attach to pin10
#define IN4 17 //right IN4 attach to pin11

#define MIN_SPD 80
#define MAX_SPD 250

void setup_motors(){
  pinMode(ENA_PIN, OUTPUT);
  pinMode(ENB_PIN, OUTPUT);
  pinMode(IN1, OUTPUT);
  pinMode(IN2, OUTPUT);
  pinMode(IN3, OUTPUT);
  pinMode(IN4, OUTPUT);
}

void moveRAT(button direction, unsigned char speed_left, unsigned char speed_right)
{
    switch(direction)
    {
        case FWD:  digitalWrite(IN1,LOW);  digitalWrite(IN2,HIGH);
                   digitalWrite(IN3,LOW);  digitalWrite(IN4,HIGH); break;
        case LFWD: digitalWrite(IN1,LOW);  digitalWrite(IN2,LOW);
                   digitalWrite(IN3,LOW);  digitalWrite(IN4,HIGH); break;
        case RFWD: digitalWrite(IN1,LOW);  digitalWrite(IN2,HIGH);
                   digitalWrite(IN3,LOW);  digitalWrite(IN4,LOW); break;
        case BCK:  digitalWrite(IN1,HIGH); digitalWrite(IN2,LOW);
                   digitalWrite(IN3,HIGH); digitalWrite(IN4,LOW); break;
        case LBCK: digitalWrite(IN1,LOW);  digitalWrite(IN2,LOW);
                   digitalWrite(IN3,HIGH); digitalWrite(IN4,LOW); break;
        case RBCK: digitalWrite(IN1,HIGH); digitalWrite(IN2,LOW);
                   digitalWrite(IN3,LOW);  digitalWrite(IN4,LOW); break;
        case RROT: digitalWrite(IN1,LOW);  digitalWrite(IN2,HIGH);
                   digitalWrite(IN3,HIGH); digitalWrite(IN4,LOW); break;
        case LROT: digitalWrite(IN1,HIGH); digitalWrite(IN2,LOW);
                   digitalWrite(IN3,LOW);  digitalWrite(IN4,HIGH); break;                   
        case STOP:
        default:   digitalWrite(IN1,HIGH);  digitalWrite(IN2,HIGH);
                   digitalWrite(IN3,HIGH);  digitalWrite(IN4,HIGH); break;
         
    }
    analogWrite(ENA_PIN,speed_left);//write speed_left to ENA_PIN,if speed_left is high,allow left motor rotate
    analogWrite(ENB_PIN,speed_right);//write speed_right to ENB_PIN,if speed_right is high,allow right motor rotate
}

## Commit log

2017-05-17 Added all the stuff
    [back_v1.stl, base_v1.stl, connections scheme - v1.fzz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]
2017-05-18 Added the Kalman filtering for Distance
2017-05-18 Updated sonar code
2017-05-18 Cleanup and stuff
    [back_v1.stl, base_v1.stl, cover_v1.stl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]
2017-05-18 conexiones actualizado
    [connections scheme - v1.fzz]
2017-05-19 Misc things
    [back_v1.stl, base_v1.stl, cover_v1.stl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]
2017-05-19 Deleted uneeded files (they're all in RAT_Sprint_2.zip)
    [back_v1.stl, base_v1.stl, cover_v1.stl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]
2017-05-19 Added sprint 4 zip and 3d pieces + cleaned up Magneto lib folder
    [base_v2.stl, mistery_piece_v2.stl, tapa_v2.stl]
2017-05-22 Added magnetometer + split some files
2017-05-22 motors.h: motors function in other files now
2017-05-22 Fixed last commit's errors
    [RAT.ino, magneto.h, sonar.h]
2017-05-24 To the north
    Ara va cap al nord.
    Hem separat les funcions del transceiver
2017-05-24 Get positions
    Ara el robot reb una latitud i longitud.
    FALTA QUE RECALCULI LA POSICIÓ ON ESTÁ QUE ARA HI HA UNA RANDOM PER
    DEFECTE.
2017-05-30 AUTONOMOUS
    + GPS pos auto-update
    + Kalman
    + Sonar fixes
    [Motors.ino, RAT.ino, gps_shield-parsing.ino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]
2017-06-02 ADDED COMMENTS
    Dunno if i've done it correctly (i'm not gud at englix). Also, which group are we?
    [RAT.ino, magneto.h, motors.h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]
